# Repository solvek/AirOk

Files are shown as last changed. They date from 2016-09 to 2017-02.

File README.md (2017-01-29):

# Overview

An open sourse device which allows to control air condition in a room and publish data into cloud.

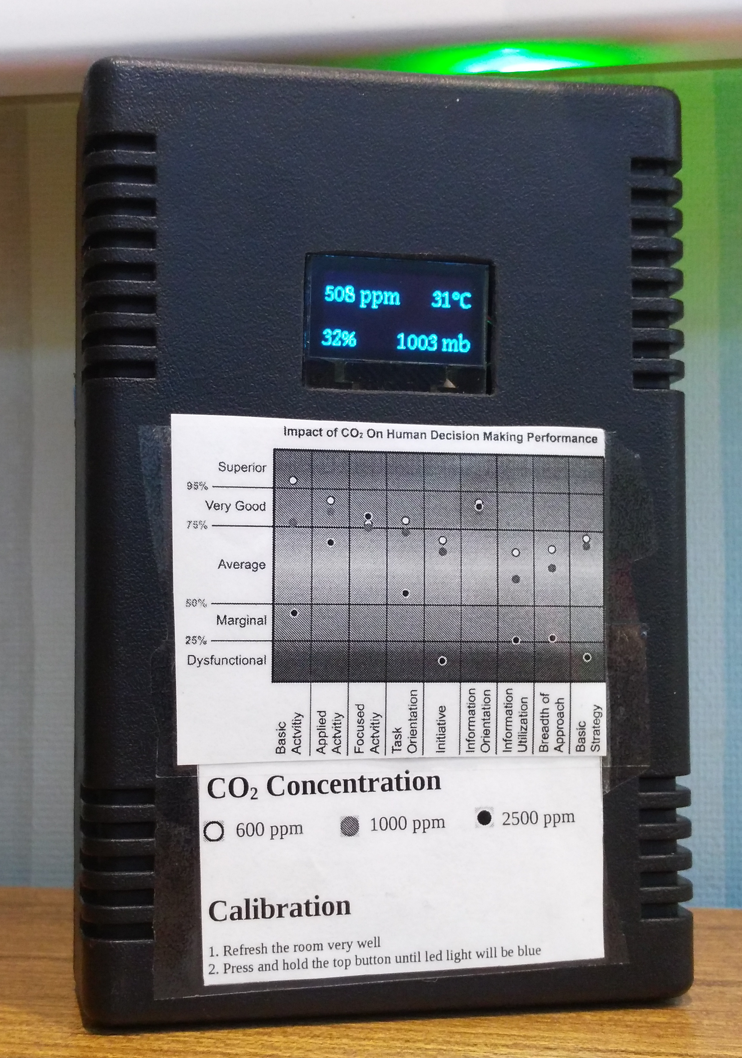
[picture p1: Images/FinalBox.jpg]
Final Look


# Features

 * CO2 concentration reading
 * Temperature reading
 * Humidity reading
 * Pressure reading
 * Display to show the values
 * Sending data to cloud via wifi
 * Button for CO2 sensor calibration
 * Red indicator for critical CO2 level

# CO2 quality

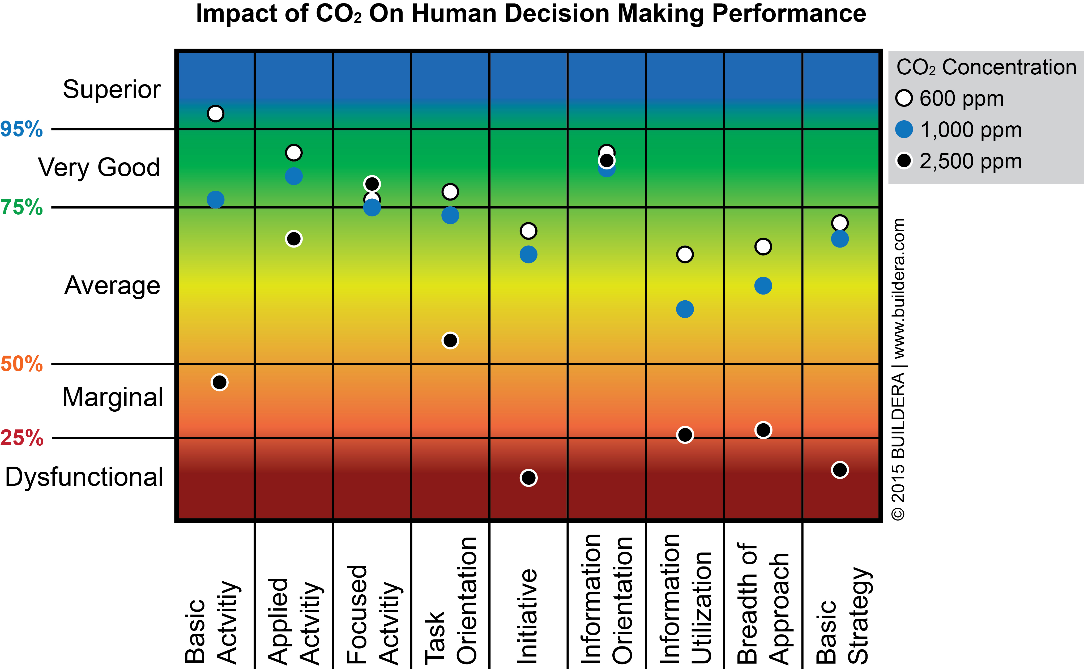
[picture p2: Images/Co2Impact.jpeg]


# Used electronic components

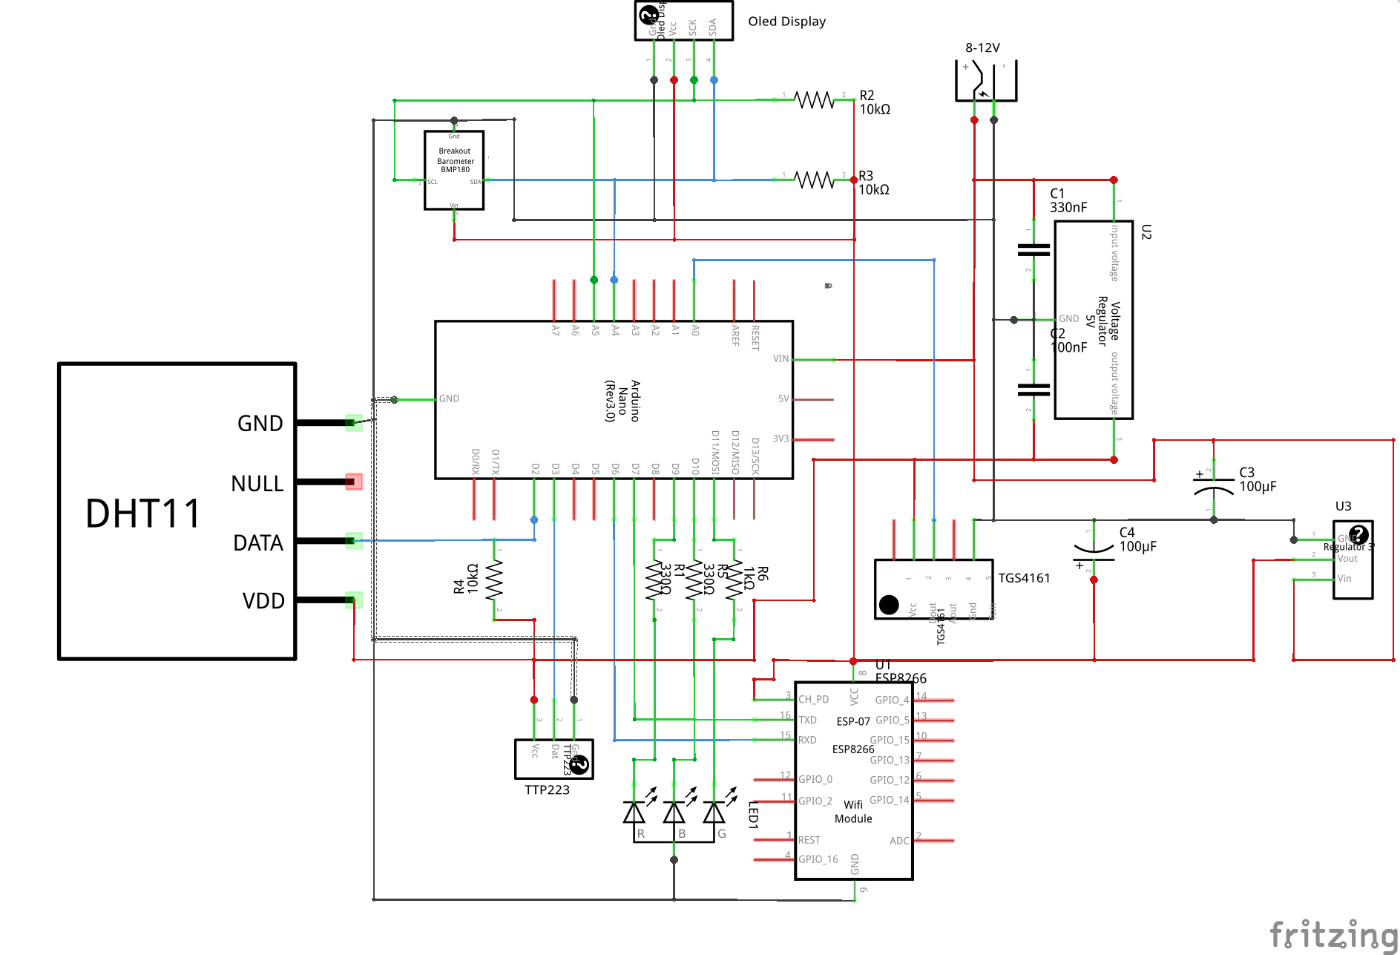
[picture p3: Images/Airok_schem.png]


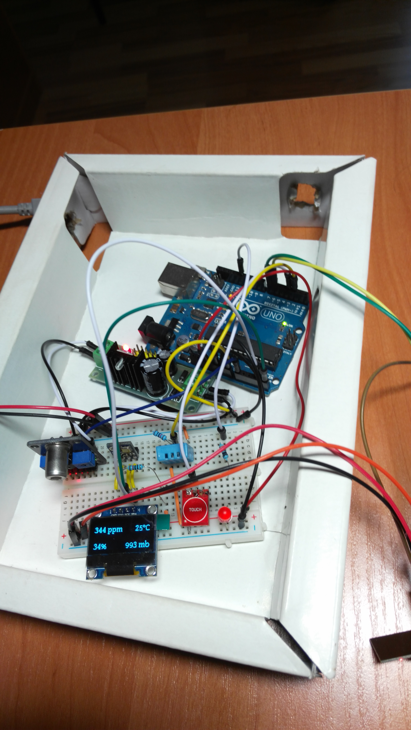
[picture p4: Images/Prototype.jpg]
Prototype. general look


[Fritzing scheme](Docs/Airok.fzz)

## Arduino Nano (or Funduino)

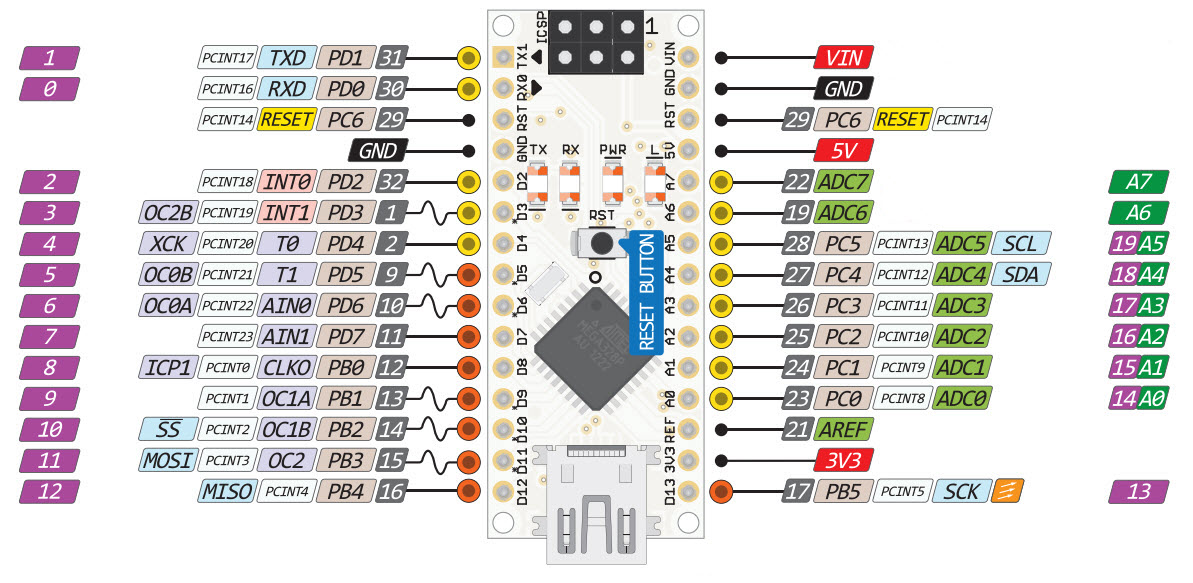
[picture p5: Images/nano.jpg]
Arduino Nano


 * [The sketch to bind everything.](Firmwares/AirOk/AirOk.ino)

 * Recommended input voltage: [7-12 V](https://www.arduino.cc/en/Main/ArduinoBoardNano)

## TGS4161 - CO2 Sensor

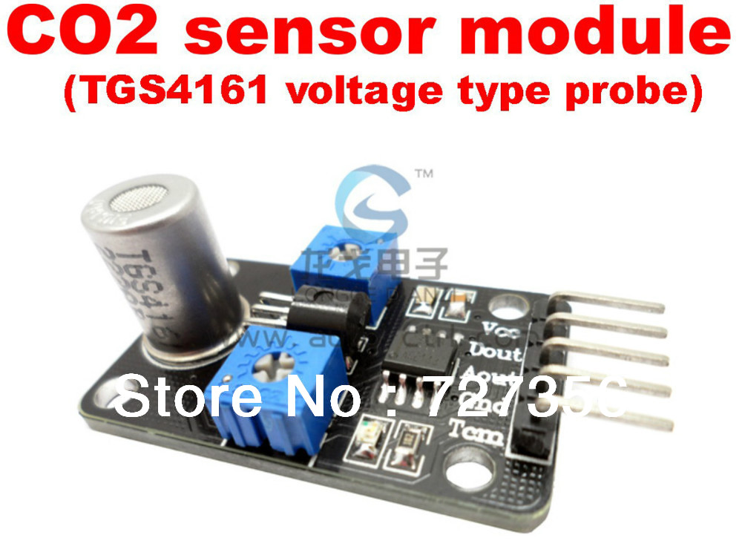
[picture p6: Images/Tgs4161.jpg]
TGS4161


  * [Library and desciption](https://github.com/solvek/CO2Sensor)

  Module based on sensor MG811 also works fine for me however it is a little bit bigger and require 6V.

## Votage stabilizer 5V

L7805

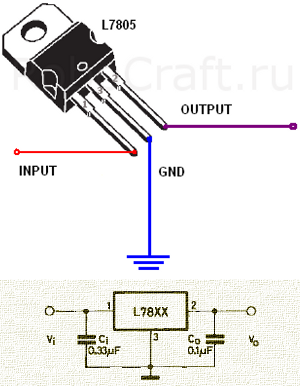
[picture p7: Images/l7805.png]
Voltage stabilizer


## Votage stabilizer 3.3V

For screen, barometer and wifi module I supply 3.3V power. For regulation of voltage I am using ATC AP1084-33 voltage regulator with a radiator.

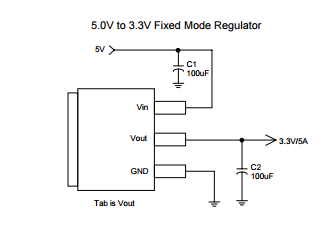
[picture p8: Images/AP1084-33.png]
3.3 Voltage Regulator


##  ESP8266 - WiFi module

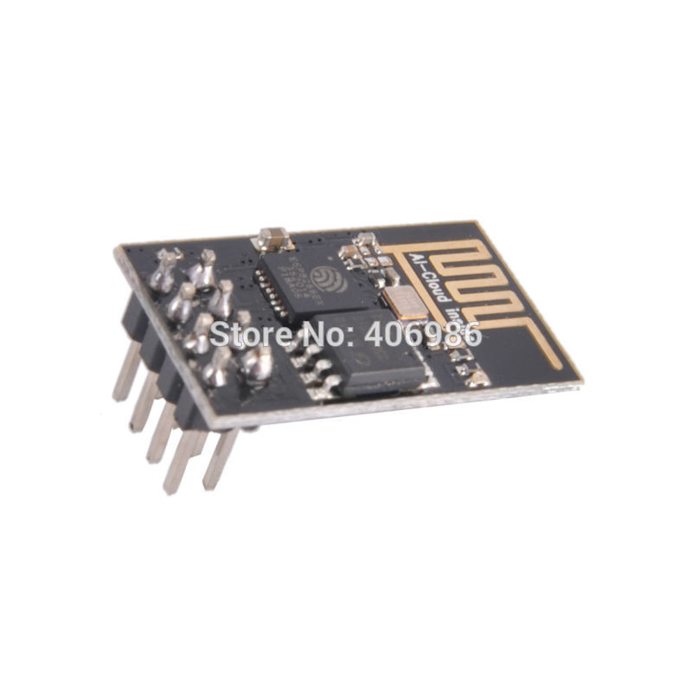
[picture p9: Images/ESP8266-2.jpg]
ESP8266


 * [AliExpress](https://www.aliexpress.com/item/ESP8266-Serial-Wireless-WIFI-Module-Transceiver-Send-Receive-LWIP-AP-STA/32229052791.html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)
 * [Pinout](Images/ESP8266.jpg)
 * [Module details (incl AT commands)](https://www.itead.cc/wiki/ESP8266_Serial_WIFI_Module)
 * [Getting Started With the ESP8266 ESP-01](http://www.instructables.com/id/Getting-Started-With-the-ESP8266-ESP-01/?ALLSTEPS)
 * [Using ESP-01 and Arduino UNO](http://www.instructables.com/id/Using-ESP-01-and-Arduino-UNO/?ALLSTEPS)
 * Baud Rate: 115200
 * My Router recognizes the device as `Espressif Inc.`

### Wires for ESP8266

In case you want to upgrade firmware connect GPIO0 to ground.

#### Top row

|GND|GPIO2|GPIO0|URXD|
|---|---|---|---|
|GND|Unwired|Unwired|D7|
|Black|None|Brown|Green|

#### Bottom row

|UTXD|CH_PD|GPIO16|VCC|
|---|---|---|---|
|D6|3v3|Unwired|3v3|
|Blue|Red|None|Red|

### [Updating firmware](http://www.instructables.com/id/Getting-Started-With-the-ESP8266-ESP-01/step18/Miscellaneous-Different-Firmware/)

 1. Wire GPIO0 to GRD
 2. [Download Flasher](https://drive.google.com/a/jayconsystems.com/file/d/0B3dUKfqzZnlwVGc1YnFyUjgxelE/view)
 3. Firmware `bin` file is also in this archive
 4. Wire module URXD (Green) to Arduino's RX (D0)
 5. Wire module UTXD (Blue) to Arduino's TX (D1)
 6. Run flasher in windows. Run app esp8266_flasher.exe
 7. In flasher chose the firmware bin file
 8. Select com port (You can use Arduino IDE to see the port number)
 9. Specify type 0x40000080
 10. Press `Download` to start flashing

In my case I have `Failed to leave Flash mode` at the end but I just ignored this.

## BMP180 - Barometer/Temperature/Altitude sensor

Can measure pressure, temperature and altitude.

* [Library](https://github.com/sparkfun/BMP180_Breakout_Arduino_Library)
* i2c address: 0x77

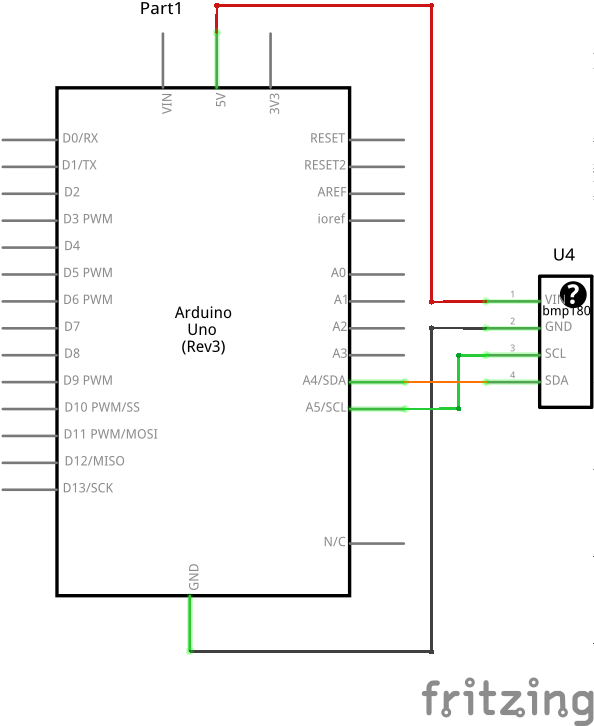
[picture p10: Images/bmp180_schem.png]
BMP180 wiring


## DHT11- Temperature and humidity sensor

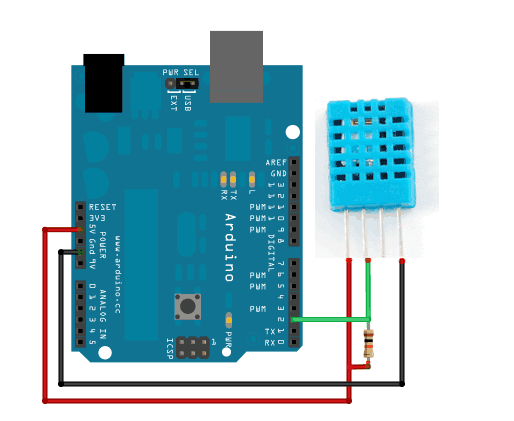
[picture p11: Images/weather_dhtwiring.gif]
DHT11 Module photo


* [DHT11 Library](https://github.com/adafruit/DHT-sensor-library)
* Input voltage: [3-5V](https://www.adafruit.com/product/386)

## Oled Display

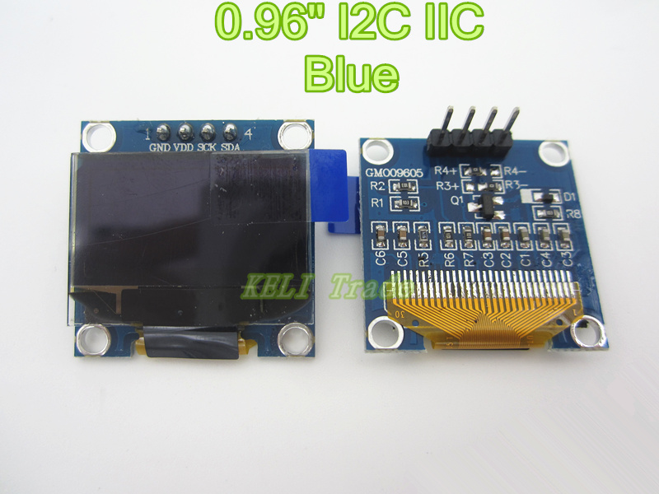
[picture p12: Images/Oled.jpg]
Oled Screen


* [AliExpress](https://www.aliexpress.com/item/Free-shipping-1Pcs-128X64-Blue-OLED-LCD-LED-Display-Module-For-Arduino-0-96-I2C-IIC/32658340632.html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)
* i2c address: 0x3c
* Protocol/Driver: SSD1306
* [Library](https://www.tindie.com/products/upgradeindustries/128x64-blue-i2c-oled-display-096-inch/)
  - [GitHub](https://github.com/olikraus/u8glib)
  - [User Reference](https://github.com/olikraus/u8glib/wiki/userreference)
  - [Fonts](https://github.com/olikraus/u8glib/wiki/fontgroup)
* Power: 3-5 V
* Resolution: 128*64
* Colors: Black and Blue
* Interface: I2C
* Screen Size: 0.96''

## TTP223 - Touch Button

  * Power: 2.5-5.5V
  * [AliExpress](https://www.aliexpress.com/item/10Pcs-TTP223-Touch-Key-Module-Self-Locking-No-Locking-Capacitive-Switches-Single-Road-Reconstruction-Module/32597879639.html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)

Trigger setting mode: (1- > Short ; 0- > No Short)

 * AB=00:No-lock High TTL level ouput;
 * AB=01:Self-lock High TTL level ouput;
 * AB=10:No-lock Low TTL level ouput;
 * AB=11:Self-lock Low TTL level ouput;

# Cloud Configuration

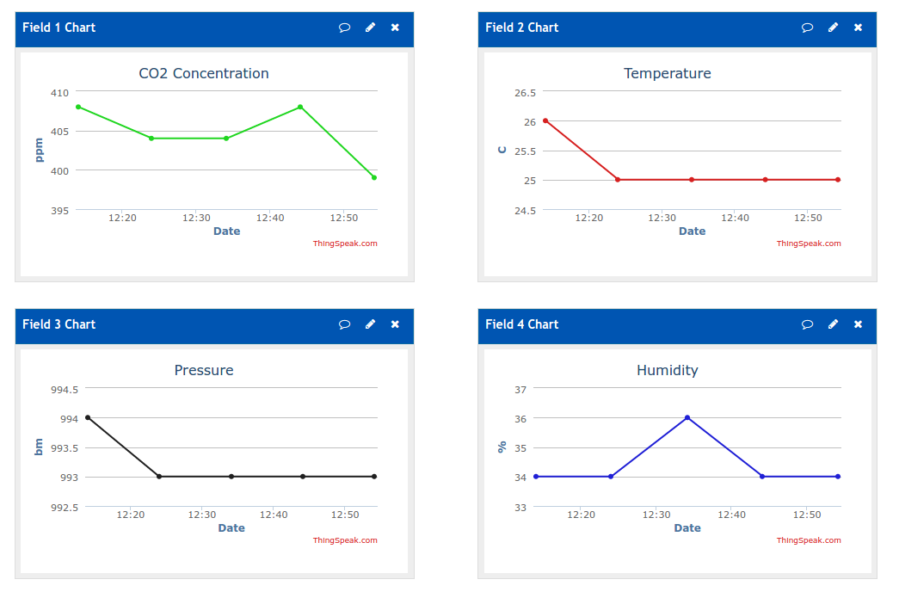
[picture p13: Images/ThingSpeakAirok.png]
ThingSpeak Charts


In order to configure wifi and cloud do the following.

 1. Make copy of `CloudSample.h` file naming it `Cloud.h` in the same directory (if you didn't do this yet)
 2. Uncomment the first line (`#define USE_CLOUD`)
 3. Register an account on [ThingSpeak](thingspeak.com) if you do not have yet
 4. Create a ThingSpeak channel
 5. Add 4 fields (CO2 concentration, Temperature, Pressure, Humidity)
 6. In section `API Keys` copy `Write API Key`
 7. Fill missing data in file `Cloud.h`

 ## Fields

|Field|Value|
|---|---|
|field1|co2|
|field2|temperature|
|field3|pressure|
|field4|humidity|

## Uploading parameters to [OpenHAB](http://openhab.org) instead of ThingSpeak

The `CloudSample.h` file contains also an alternative example for configuration of uploadint data to OpenHAB server (it is commented). You can enable persisting data on OpenHAB server and view historical charts, for example usne [RRD database](https://github.com/openhab/openhab/wiki/rrd4j-Persistence).

Some my OpenHAB configuration examples with RRD persistance are available [here](https://github.com/solvek/electronics/tree/master/meteostation3)

Notice: Currently I am using OpenHAB 1. The examples may need to be adopted if you are using OpenHAB 2+.

# Electricity Power

Current Measure

## 12 V adapter

### With WiFi

 * Power: 3 W
 * Current: 240 mA

### Without WiFi

 * Power: 1.9 W
 * Current: 160 mA

# Enclosing into a box

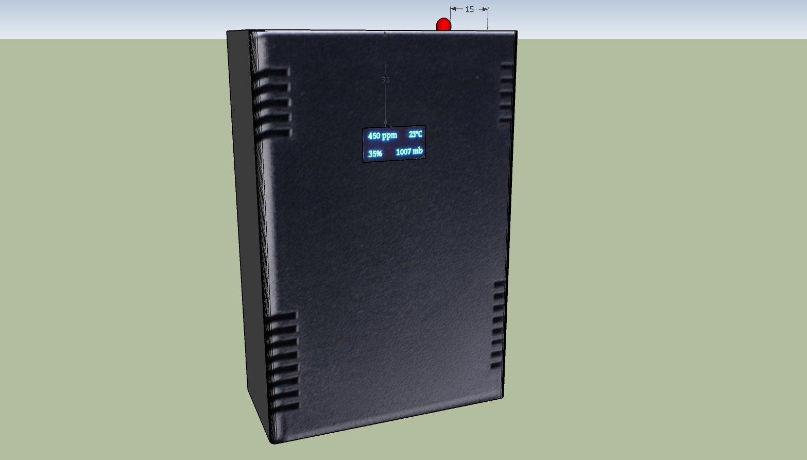
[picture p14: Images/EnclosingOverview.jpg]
Enclosing Overview


 * [The box on AliExpress](https://www.aliexpress.com/item/Free-shipping-135-90-45mm-1-pcs-project-box-plastic-desk-top-electronic-enclosure-distribution-box/32685307900.html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)
 * Sizes: `135*90*45`
 * [Sketchup Model](Docs/Enclosing.skp)

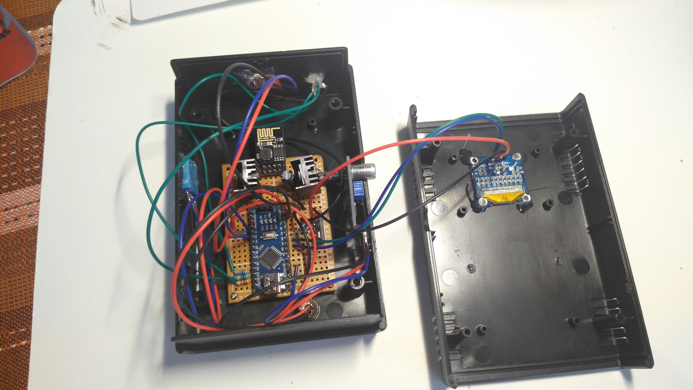
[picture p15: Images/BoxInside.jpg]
Motheboard


## Wires

### Input power (9V)
|Main Board|External|Wire color|
|---|---|---|
|Ground|GND|Black|
|9V|VDD|Red|

### RGB Lamp

|Main Board|External|Wire color|
|---|---|---|
|Ground|GND|Black|
|D9|Red|Green|
|D11|Green|Green|
|D10|Blue|Green|

### DHT11 sensor

|Main Board|External|Wire color|
|---|---|---|
|Ground|GND|Black|
|5V|VDD|Red|
|D2|Data|Blue|

### Touch Button

|Main Board|External|Wire color|
|---|---|---|
|Ground|GND|Black|
|5V|VDD|Red|
|D3|Dat|Blue|

### TGS4161

|Main Board|External|Wire color|
|---|---|---|
|Ground|GND|Black|
|5V|VCC|Red|
|A0|AOUT|Blue|

### OLED Screen

|Main Board|External|Wire color|
|---|---|---|
|Ground|GND|Black|
|3V3|VDD|Red|
|A4|SDA|Blue|
|A5|SCK|Green|

# External Links

 * [Sleep Monitor](https://learn.adafruit.com/schluff-the-oshw-sleep-monitor)

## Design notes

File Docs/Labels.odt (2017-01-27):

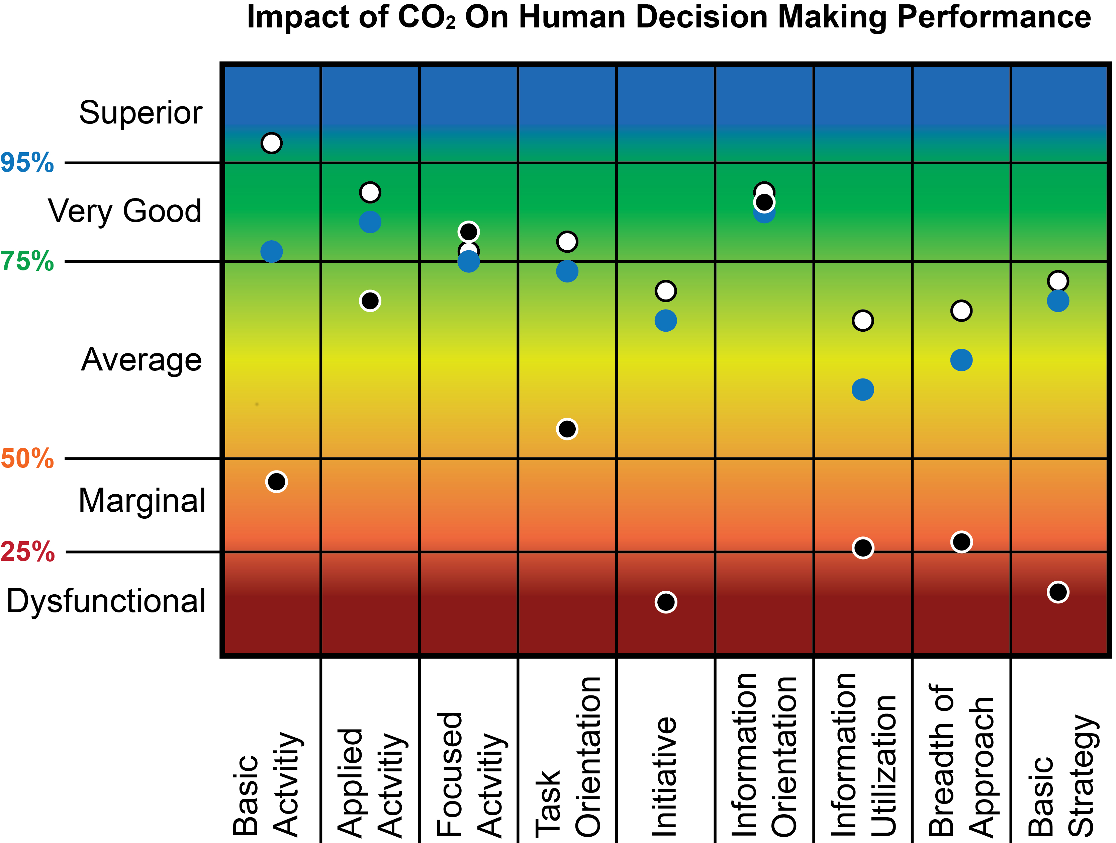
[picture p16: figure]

CO2 Concentration
| 600 ppm | | 1000 ppm | | 2500 ppm
Calibration
1. Refresh the room very well 2. Press and hold the top button until led light will be blue

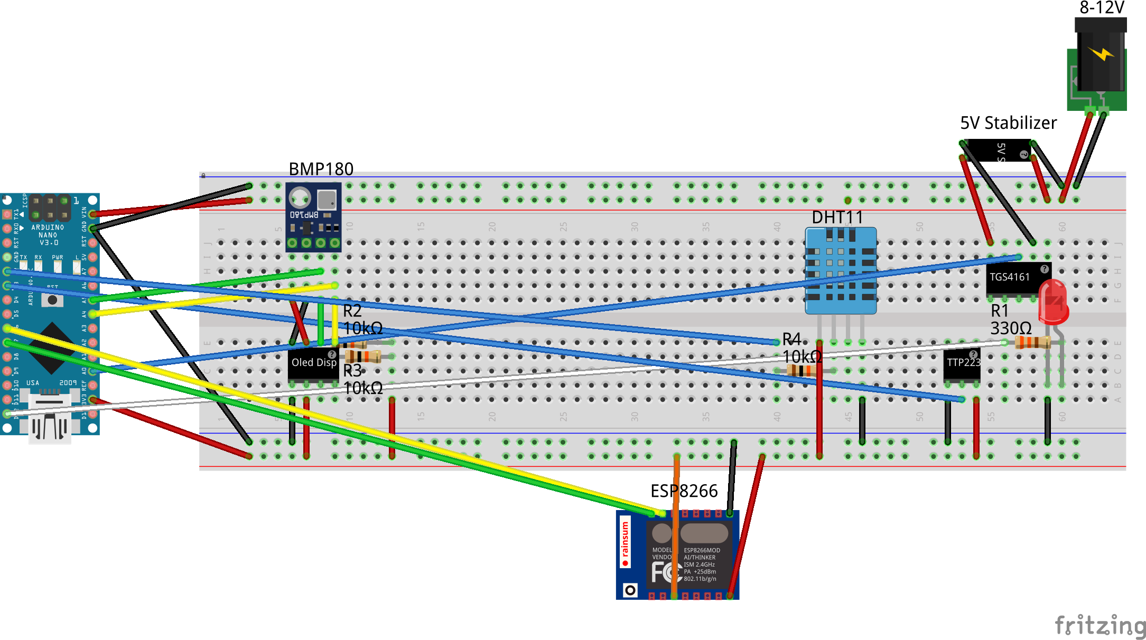
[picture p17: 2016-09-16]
Images/Airok_bb.png

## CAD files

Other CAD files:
Docs/Enclosing.skp

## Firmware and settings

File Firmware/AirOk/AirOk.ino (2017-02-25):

#include <Wire.h>
#include <U8glib.h>

#include <CO2Sensor.h>
#include <SFE_BMP180.h>
#include "DHT.h"

// If the file is missing, make a copy of CloudSample.h naming it Cloud.h
#include "Cloud.h"

#ifdef USE_CLOUD
#include <SoftwareSerial.h>
#endif

#define UNDEFINED -1

#define LOG_WIFI
//#define LOG_DATA

//////////////////////////////////////
// Pins configuration
#define PIN_CO2_AOUT A0
//#define PIN_CO2_DOUT 5
#define PIN_DHT 2
#define PIN_BUTTON 3
#define PIN_LED_RED 9
#define PIN_LED_GREEN 11
#define PIN_LED_BLUE 10
#define PIN_WIFI_RX 6
#define PIN_WIFI_TX 7

//////////////////////////////////////
// Temperature calibration
// t = (t0*TC_A-TC_B)/TC_C
#define TC_A 3
#define TC_B 45
#define TC_C 2

//////////////////////////////////////
// Timing configuration
// Period of updating data from sensors and displaying
#define PERIOD_UPDATE 100L
// Period of sending data to cloud
#define PERIOD_SEND 5*60*1000L
//#define PERIOD_SEND 30*1000L

CO2Sensor co2sensor(PIN_CO2_AOUT, 0.999, 20);
SFE_BMP180 bmp;
DHT dht(PIN_DHT, DHT11);

#ifdef USE_CLOUD
SoftwareSerial wifi(PIN_WIFI_RX, PIN_WIFI_TX);
#endif

U8GLIB_SSD1306_128X64 u8g(U8G_I2C_OPT_NONE|U8G_I2C_OPT_DEV_0);

long lastUpdateDataTime;
long lastSendDataTime;

struct {
  int co2;
  int temperature;
  int pressure;
  int humidity;
} airok;

int co2raw;

void setup() {
  pinMode(PIN_LED_RED, OUTPUT);
  pinMode(PIN_LED_GREEN, OUTPUT);
  pinMode(PIN_LED_BLUE, OUTPUT);
  pinMode(PIN_BUTTON, INPUT);

  #ifdef PIN_CO2_DOUT
  pinMode(PIN_CO2_DOUT, INPUT);
  #endif
  
  Serial.begin(115200);
  Serial.println(F("=== Air'OK started ==="));

#ifdef USE_CLOUD
  wifi.begin(115200);
  connectWifi();  
#endif

  u8g.setColorIndex(1);

  if (!bmp.begin()) {
//    Serial.println("Could not find a valid BMP180 sensor, check wiring!");
  }

  dht.begin();

  co2sensor.calibrate();

  updateData();

  lastUpdateDataTime = 0;
  lastSendDataTime = 0;
}

void loop() {  
  long now = millis();
  if (now - lastUpdateDataTime > PERIOD_UPDATE){  
//    Serial.print("now: ");
//    Serial.println(now);
//    Serial.print("lastUpdateDataTime: ");
//    Serial.println(lastUpdateDataTime);
//    Serial.print("Dif: ");
//    Serial.println(now-lastUpdateDataTime);    
//    Serial.print("PERIOD_UPDATE: ");
//    Serial.println(PERIOD_UPDATE);    
    updateData();
    lastUpdateDataTime = now;
  }

#ifdef USE_CLOUD
  if (now - lastSendDataTime > PERIOD_SEND){
//    Serial.print(F("now: "));
//    Serial.println(now);
//    Serial.print(F("lastSendDataTime: "));
//    Serial.println(lastSendDataTime);
//    Serial.print(F("Dif: "));
//    Serial.println(now-lastSendDataTime);    
//    Serial.print(F("PERIOD_SEND: "));
//    Serial.println(PERIOD_SEND);
    sendDataToCloud();
//    delay(1000);
//    disconnectWifi();
    lastSendDataTime = now;
  } 
#endif
 
  pictureLoop();
  checkButton();
}

//////////////////////////////////////
// Data
void updateData(){
//  Serial.println(F("Reading data"));
  airok.co2 = readCo2();
  co2raw = co2sensor.getVoltage();

#ifdef LOG_DATA
  Serial.print(F("CO2: "));
  Serial.print(airok.co2);
  Serial.print(F(", CO2 Raw: "));
  Serial.println(co2raw);
#endif

  #ifdef PIN_CO2_DOUT
  int isCritical = digitalRead(PIN_CO2_DOUT);
  digitalWrite(PIN_LED_GREEN, LOW);
  digitalWrite(PIN_LED_RED, isCritical);  
  #else
  analogWrite(PIN_LED_GREEN, co2sensor.getGreenLevel());
  analogWrite(PIN_LED_RED, co2sensor.getRedLevel());
  #endif

#ifdef LOG_DATA
  Serial.print(F("CO2 concentration: "));
  Serial.print(airok.co2);
  Serial.println(F(" ppm"));
#endif

  airok.temperature = readDhtTemperature();
  airok.humidity = readHumidity();

#ifdef LOG_DATA
  Serial.print(F("DHT Temperature: "));
  Serial.println(airok.temperature);
#endif

  double temperature2;

  temperature2 = readBmpTemperature();
  if (airok.temperature == UNDEFINED) airok.temperature = temperature2;
  else if (temperature2 != UNDEFINED) airok.temperature = (airok.temperature+temperature2)/2;

  if (airok.temperature != UNDEFINED) airok.temperature = (airok.temperature*TC_A-TC_B)/TC_C;

  airok.pressure = (temperature2 == UNDEFINED) ?
    UNDEFINED :
    readPressure(temperature2);

#ifdef LOG_DATA
  Serial.print("BMP Temperature: ");
  Serial.println(temperature2);
  Serial.print("BMP pressure: ");
  Serial.println(airok.pressure);
#endif
}

int readCo2(){
  return co2sensor.read();
}

double readBmpTemperature(){
  double t;
  
  char status = bmp.startTemperature();
  if (status == 0){
//    Serial.println("error starting temperature measurement");
    return UNDEFINED;
  }
  
  delay(status);
  
  status = bmp.getTemperature(t);
  if (status == 0){
//    Serial.println("error retrieving temperature measurement\n");
    return UNDEFINED;
  }

  return t;
}

double readPressure(double tmp){
  double pressure;
  
  char status = bmp.startPressure(3);
  if (status == 0){
//    Serial.println("error starting pressure measurement\n");
    return UNDEFINED;
  }
  
  delay(status);
  
  status = bmp.getPressure(pressure, tmp);
  
  if (status == 0){
//    Serial.println("error retrieving pressure measurement\n");
    return UNDEFINED;
  }

  return pressure;
}

int readDhtTemperature(){
  int temperature = dht.readTemperature();
  if (isnan(temperature)) {
//    Serial.println("Failed to read temperature from DHT sensor!");
    return UNDEFINED;
  }
  return temperature;
}

int readHumidity(){
  int humidity = dht.readHumidity();
  if (isnan(humidity)) {  
//    Serial.println("Failed to read humidity from DHT sensor!");
    return UNDEFINED;
  }
  return humidity;
}

//////////////////////////////////////
// Control
void checkButton(){
  if (digitalRead(PIN_BUTTON) == LOW) return;  

  co2sensor.calibrate();  

  digitalWrite(PIN_LED_GREEN, LOW);
  digitalWrite(PIN_LED_RED, LOW);
  
  digitalWrite(PIN_LED_BLUE, LOW);
  delay(100);
  digitalWrite(PIN_LED_BLUE, HIGH);
  delay(500);
  digitalWrite(PIN_LED_BLUE, LOW);

  while(digitalRead(PIN_BUTTON) == HIGH);
}

//////////////////////////////////////
// Display
#define WIDTH 128
#define HEIGHT 64

void pictureLoop(){
  u8g.firstPage();  
  do {
    draw();
  } while( u8g.nextPage() ); 
}

void draw() {
  u8g.setFont(u8g_font_gdr12);
  String s = String(airok.co2)+" ppm";
  u8g.drawStr(0, 25, s.c_str());

  s = String(airok.temperature)+(char)176+"C";
  char* c = s.c_str();
  int w = u8g.getStrWidth(c);
  u8g.drawStr(WIDTH-w, 25, c);

  s = String(airok.humidity)+"%";
  u8g.drawStr(0, 62, s.c_str());

  s = String(airok.pressure)+" mb";
  c = s.c_str();
  w = u8g.getStrWidth(c);
  u8g.drawStr(WIDTH-w, 62, c);
}

//////////////////////////////////////
// Cloud
#ifdef USE_CLOUD
#define WIFI_TIMEOUT 5000

#define SEPARATOR  F("&")

void sendDataToCloud(){
  Serial.println(F("Sending data to server"));
  
  String cmd = F("AT+CIPSTART=\"TCP\",\"");
  cmd += CLOUD_IP;
  cmd += F("\",");
  cmd += CLOUD_PORT;
  sendWifiCommand(cmd, F("OK"));

  String req = CLOUD_GET;
  req += CLOUD_FIELD_CO2;
  req += airok.co2;
  req += SEPARATOR;
  req += CLOUD_FIELD_TEMPERATURE;
  req += airok.temperature;
  req += SEPARATOR;
  req += CLOUD_FIELD_PRESSURE;
  req += airok.pressure;
  req += SEPARATOR;
  req += CLOUD_FIELD_HUMIDITY;
  req += airok.humidity;

  #ifdef CLOUD_FIELD_CO2_RAW
  req += SEPARATOR;
  req += CLOUD_FIELD_CO2_RAW;
  req += co2raw;    
  #endif

  cmd = F("AT+CIPSEND=");
  cmd += (req.length()+2);
  sendWifiCommand(cmd, ">");

  sendWifiCommand(req, F("OK"));

  delay(1000);
  sendWifiCommand(F("AT+CIPCLOSE"), F("OK"));  
}

void connectWifi(){ 
// Serial.println("Connecting wifi");
 delay(5000);
 sendWifiCommand(F("AT+RST"), F("ready")); 
 
 sendWifiCommand(F("AT+CWMODE=1"), "OK"); 

 String auth = F("AT+CWJAP=\"");
 auth +=CLOUD_SSID;
 auth += F("\",\"");
 auth +=CLOUD_PASS;
 auth +=F("\"");
#ifdef LOG_WIFI
 Serial.print("Auth: ");
 Serial.println(auth);
#endif
 sendWifiCommand(auth, "OK");

#ifdef LOG_WIFI 
// Print current network parameters
 sendWifiCommand("AT+CIFSR", "OK");
#endif

// This command takes the wifi to low energy (sleep) mode for provided time in ms but it doesn't wake up for me
// sendWifiCommand("AT+GSLP=10000", "OK");
}

void disconnectWifi(){ 
  sendWifiCommand(F("AT+CWQAP"), "OK");
}

bool sendWifiCommand(String command, String ack){
#ifdef LOG_WIFI
  Serial.print("Sending command: ");
  Serial.println(command);
#endif

  wifi.println(command);
  if (expectResponse(ack))
    return true;
  else{
#ifdef LOG_WIFI
    Serial.println("Failed to execute command");
#endif
    return false;
  }
}

bool expectResponse(String keyword){
 byte current_char = 0;
 byte keyword_length = keyword.length();
 long deadline = millis() + WIFI_TIMEOUT;
 while(millis() < deadline){
  if (wifi.available()){
    char ch = wifi.read();
#ifdef LOG_WIFI
    Serial.write(ch);
#endif
    if (ch == keyword[current_char])
      if (++current_char == keyword_length){
#ifdef LOG_WIFI        
       Serial.println();
#endif
       return true;
    }
   }
  }
 return false; // Timed out
}
#endif

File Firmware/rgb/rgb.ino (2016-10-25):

/*
Adafruit Arduino - Lesson 3. RGB LED
*/
 
int redPin = 10;
int greenPin = 11;
int bluePin = 9;
 
//uncomment this line if using a Common Anode LED
//#define COMMON_ANODE
 
void setup()
{
  pinMode(redPin, OUTPUT);
  pinMode(greenPin, OUTPUT);
  pinMode(bluePin, OUTPUT);  
}
 
void loop()
{
  setColor(0, 0, 255);
  delay(1000);
  
  setColor(0, 255, 0);
  delay(500);

  for (int i=0;i<255;i++){
    setColor(i, 255-i, 0);
    delay(50);    
  }
  
  setColor(255, 0, 0);
  delay(1000);
}
 
void setColor(int red, int green, int blue)
{
  #ifdef COMMON_ANODE
    red = 255 - red;
    green = 255 - green;
    blue = 255 - blue;
  #endif
  analogWrite(redPin, red);
  analogWrite(greenPin, green);
  digitalWrite(bluePin, blue);  
}

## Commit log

2016-09-15 Implemented calibration
2016-09-15 Reading bmp and displaying temperature
2016-09-15 Reading temperature and humidity from Dht moduel
2016-09-16 Drew breadboard scheme in Fritzing
    [Airok.fzz]
2016-09-16 Scheme drawing
    [Airok.fzz]
2016-09-19 Added confirmation of callibration by blinking led
    [Airok.fzz]
2016-09-19 Added image of prototype
2016-09-19 Fixed way how resistor is connected to dht11
    [Airok.fzz]
2016-09-20 Added current mesurement information
2016-09-22 Experienting with saving energy of wifi
    [Boards.fzz]
2016-10-19 Updated the scheme
    [Airok.fzz]
2016-10-19 Added capacitors
    [Airok.fzz]
2016-10-24 Added enclosing box model
    [Airok.fzz, Enclosing.skp]
2016-10-24 Sketch now supports rgb indicator
    [Enclosing.skp]
2016-10-25 Fixed pin numbers for rgb
    [AirOk.ino, rgb.ino]
2016-11-07 Updated and fixed scheme. Updated documentation
    [Airok.fzz]
2016-11-09 Improved info about wiring esp-01
    [Airok.fzz]
2017-01-22 Using temperature value from DHT only
2017-01-22 Still having wifi issues
    [AirOk.ino]
2017-01-27 Added chart with co2 impact. Added label for printing
2017-01-29 1. Added temperature calibration feature 2. Added couple of images of the final device
2017-01-29 Changed temperature calibration values
2017-02-25 Added temperature calibration
